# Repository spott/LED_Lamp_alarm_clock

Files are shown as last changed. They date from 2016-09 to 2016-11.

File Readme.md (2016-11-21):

# An LED alarm clock.  

Also known as a ESP8266 controlled PWM driver, lowish power AC Dimmer, and relay driver.  The schematic is available in PDF form in the PDFs folder, along with the PCB layout.

The ESP controls three different things here:

In the top right of the board, there are two optocouplers.  The ESP reads the voltage across the AC line using the ADC pin, and turns on a triac with GPIO12 (the `AC_CTRL1` net).  It can also turn on an SSR, a relay switch or some other load using `AC_CTRL2`.  `AC_CTRL2` and associated circuitry is on the left underneath the SMPS.

The bottom of the board contains the PWM control chip.  It has 16 LED outputs, of which 15 are broken out, and drive low V_th, and low gate charge N channel MOSFETs.  These act as low side switches for the pins that are next to them.  At the moment, the limit on the current that each can drive is the connector is the connector I believe.

This board is driven by a 12V input on the left side of the board, above the relay output.  The 12V is guided around the outside of the board in a rather wide copper pour on the bottom of the board, and is also used as the Vin of a SMPS that generates the 3.3V power for the ESP and PWM chip.

## Programming the board:

The programming of the ESP is done with a push switch (when the LED is lighted, the board is ready to run, when it is off, the board is waiting to be programmed), and a reset switch (the switch pulls reset low).  When the board is waiting to be programmed, a low signal on the DTR pin of the FTDI cable pulls CH_PD low, along with GPIO0 (hopefully, in case the switch is in the wrong position).

## Software:

Kicad 4.0.4 mostly, though some work was done with Kicad Master branch.

If you have trouble opening it with Kicad 4.0.4, submit an issue and I'll take care of it.

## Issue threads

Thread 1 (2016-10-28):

Reset method?

spott, 2016-10-28:
Maybe needs another reset method (either a way to power cycle the chip, or pull CH_PD low?

spott, 2016-11-06:
So, I think the best way to do this is using the `ck` upload_restartmethod in esptool and pio.

This means `RTS` controls RESET or CH_PD, `DTR` controls GPIO0.  This appears to work.

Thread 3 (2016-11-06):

Power supply stability control

spott, 2016-11-06:
* increase voltage of PS (will prevent brownouts from voltage dropping too low on current surge).
* increase capacitance near esp?

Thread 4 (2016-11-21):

footprint for mosfets flips source and gate.

spott, 2016-11-21:
:(  This kills the board.

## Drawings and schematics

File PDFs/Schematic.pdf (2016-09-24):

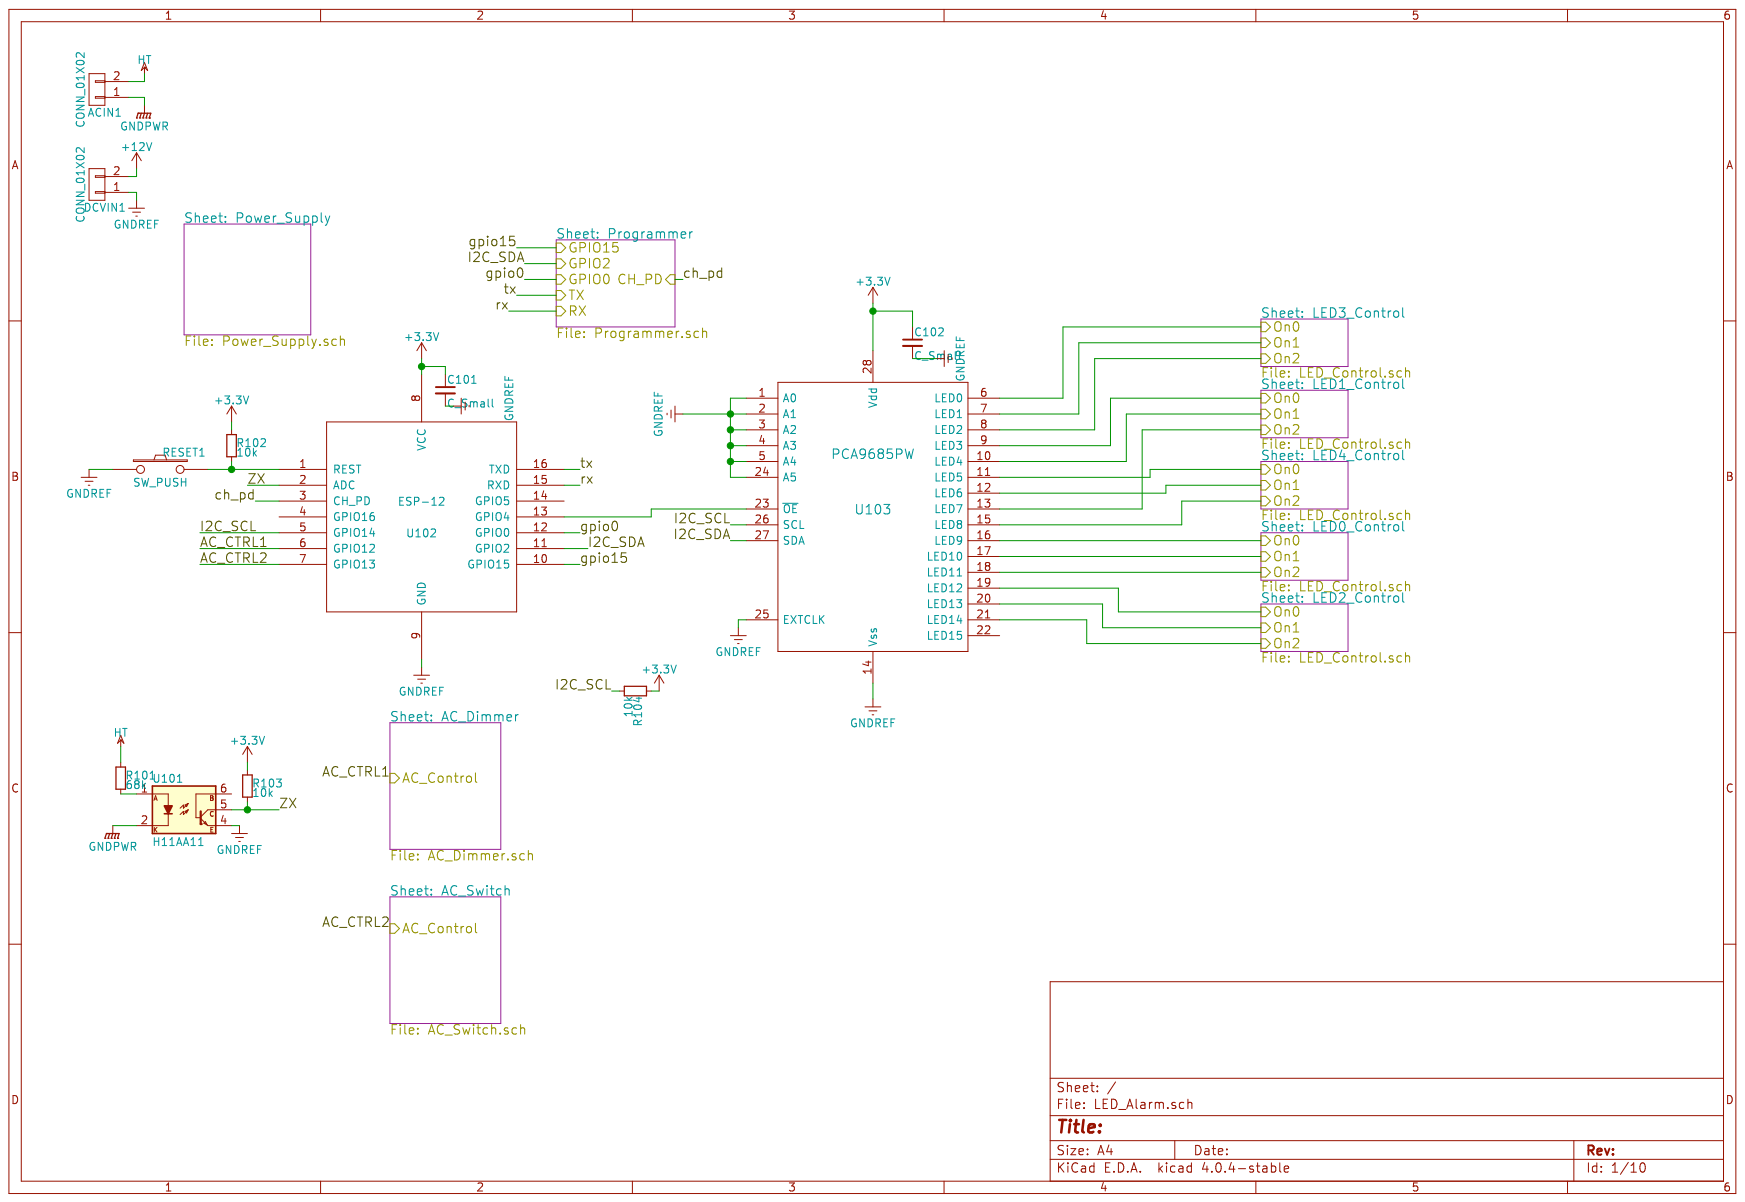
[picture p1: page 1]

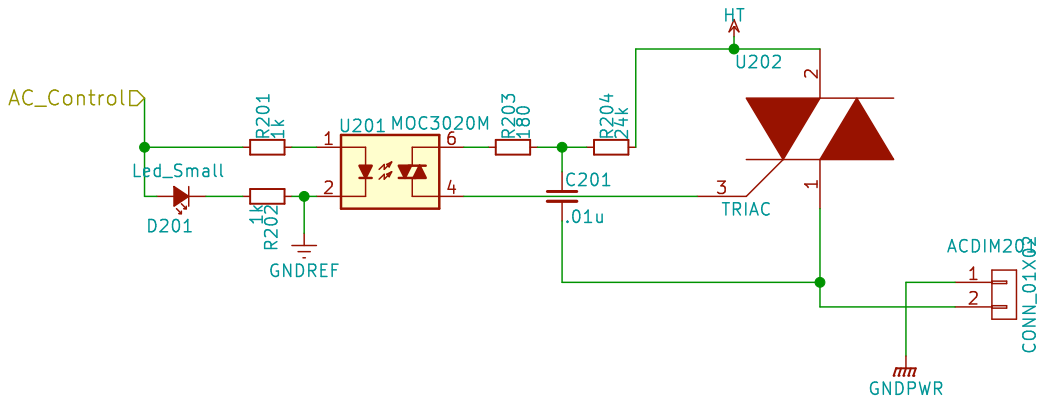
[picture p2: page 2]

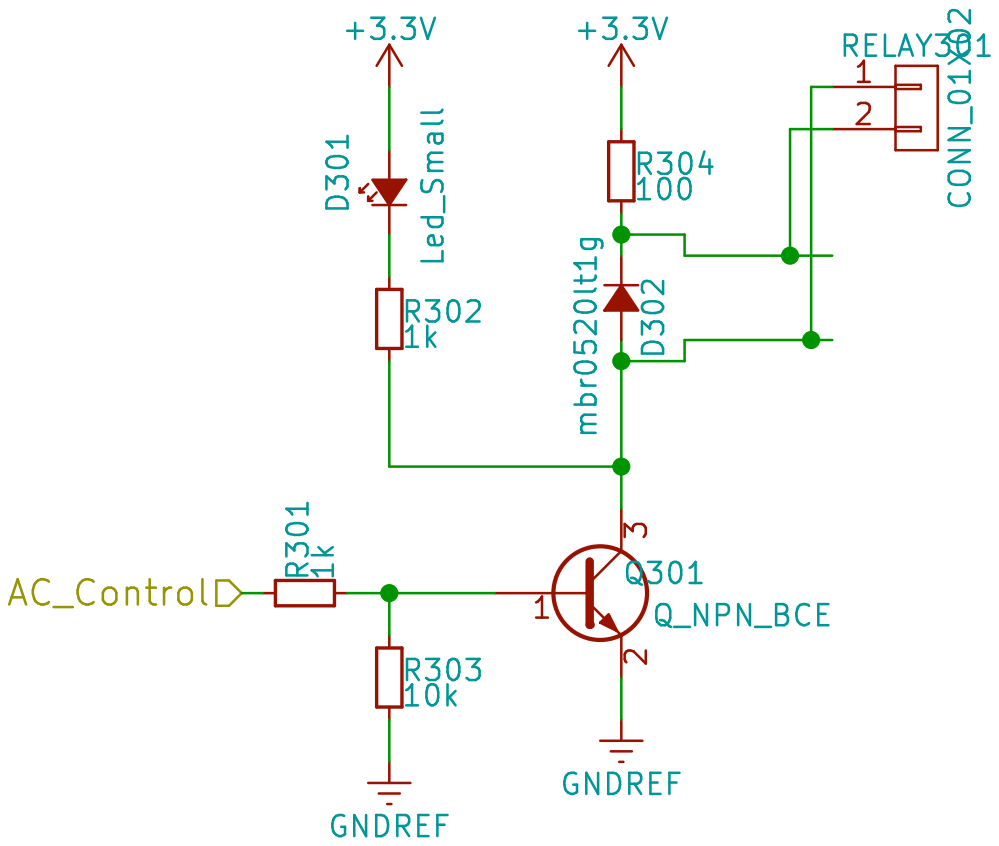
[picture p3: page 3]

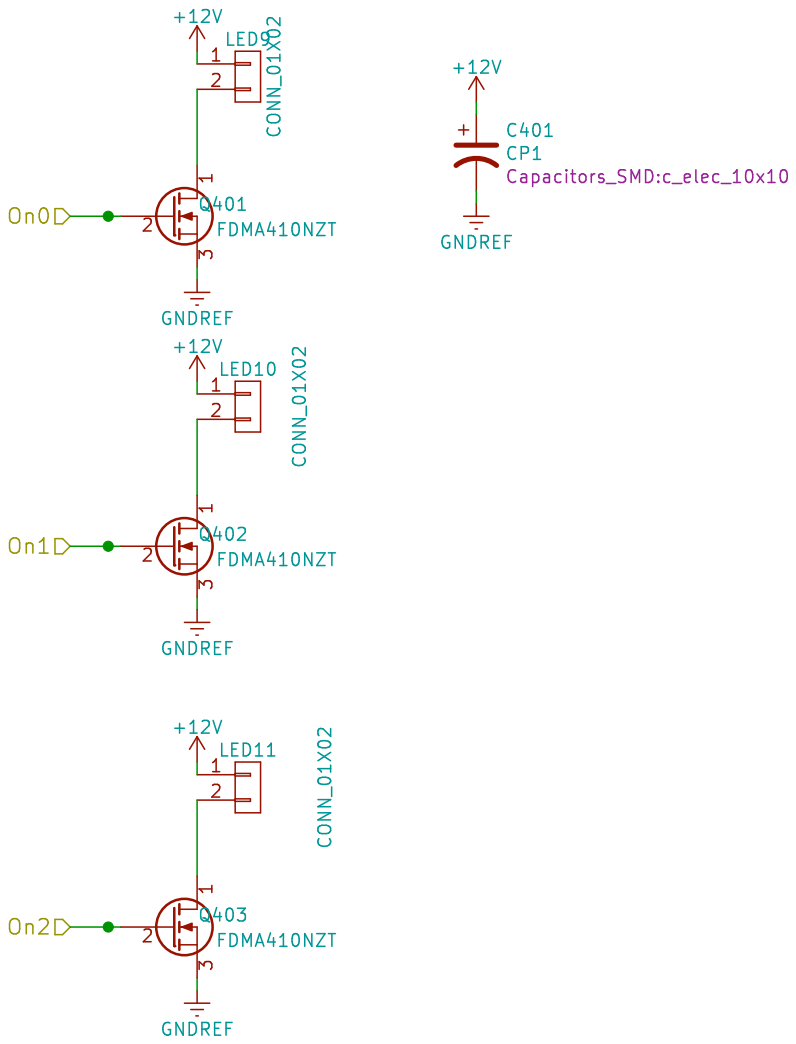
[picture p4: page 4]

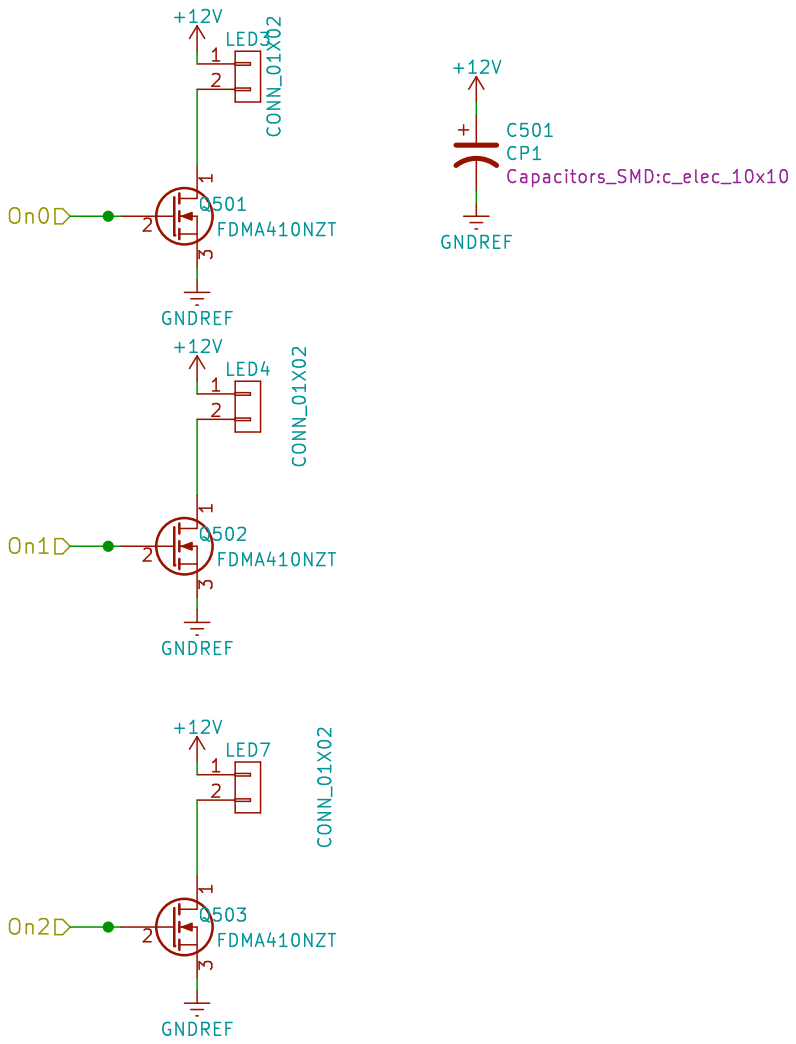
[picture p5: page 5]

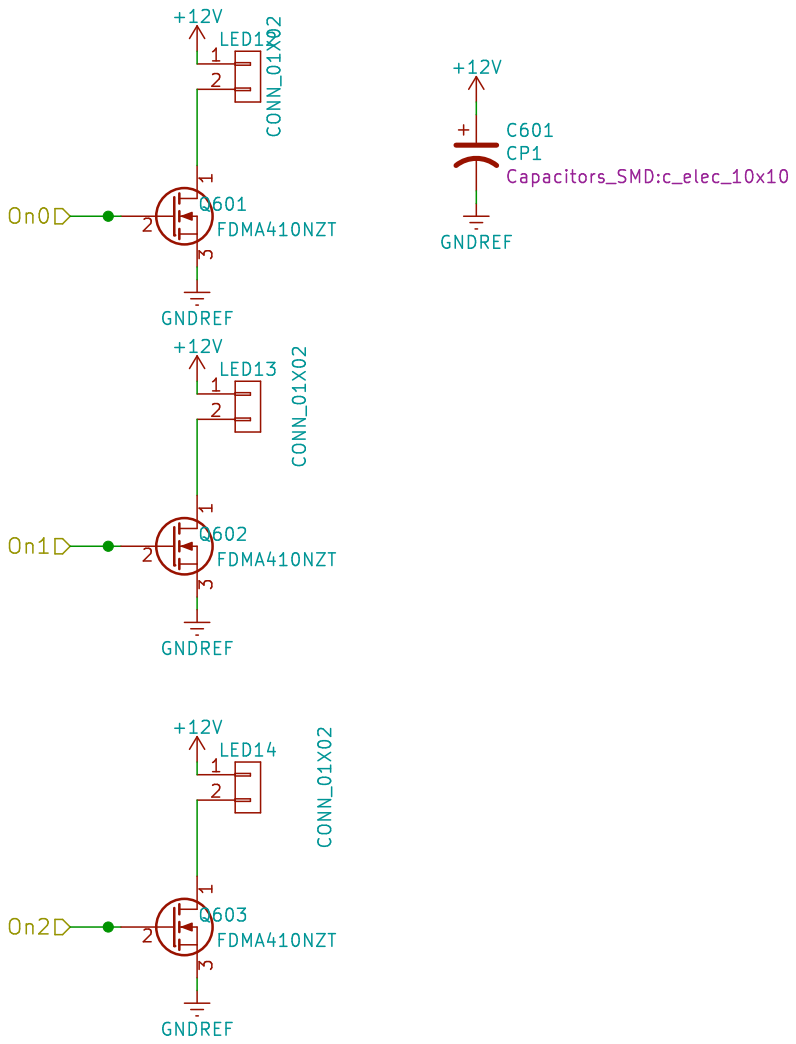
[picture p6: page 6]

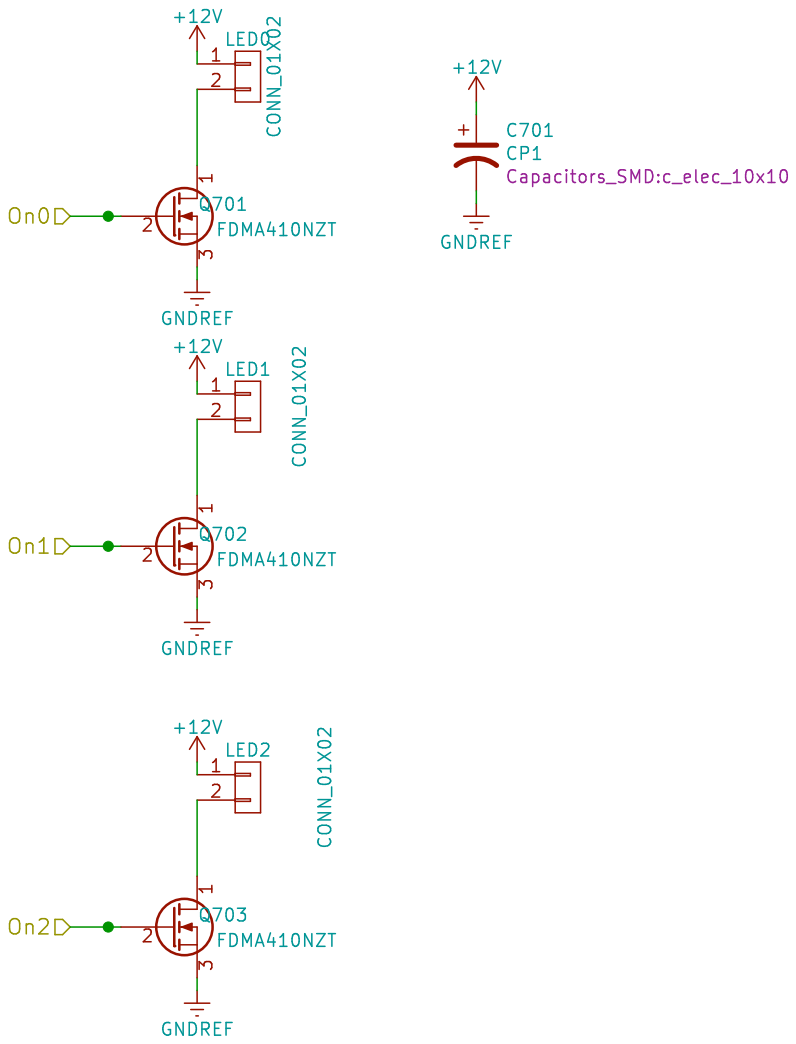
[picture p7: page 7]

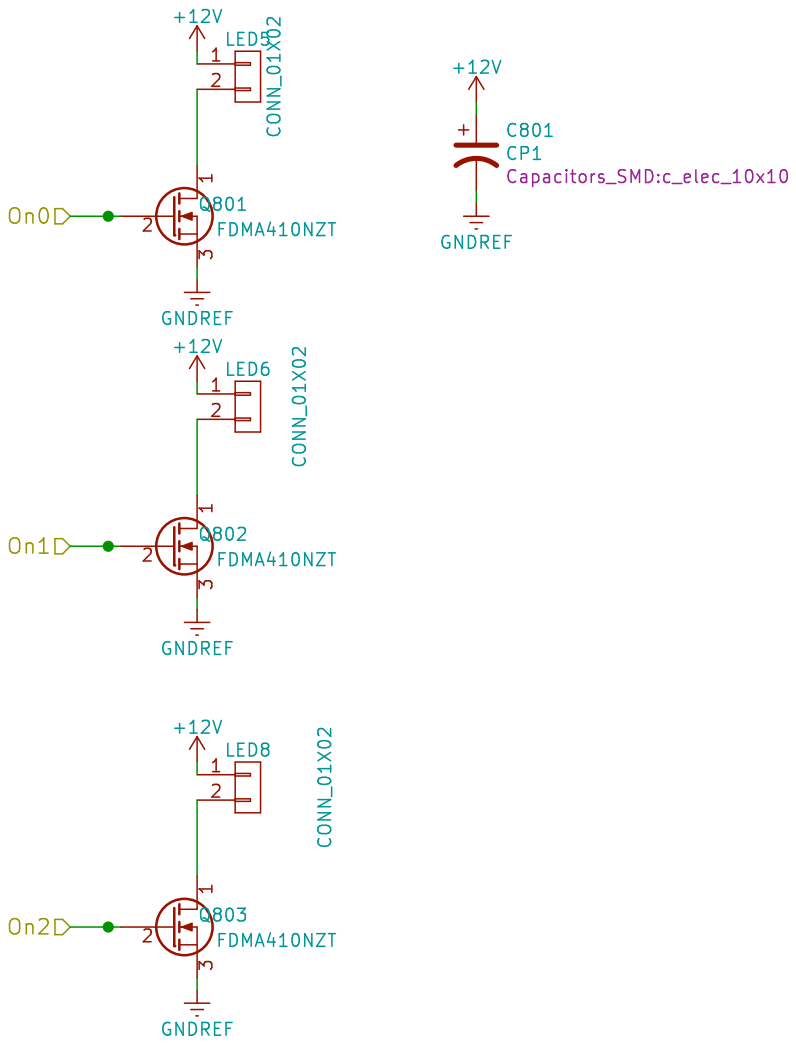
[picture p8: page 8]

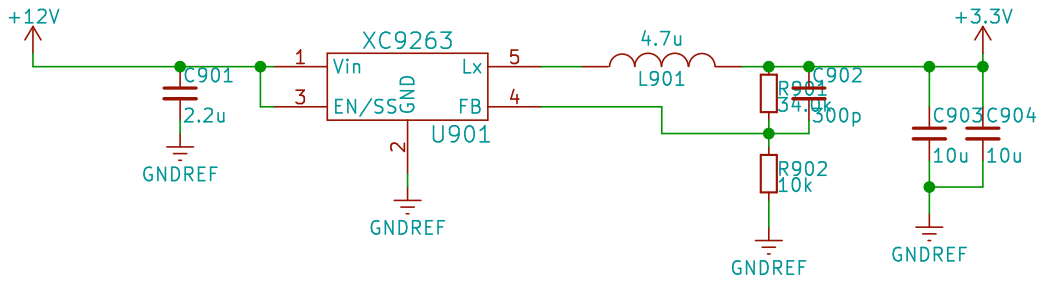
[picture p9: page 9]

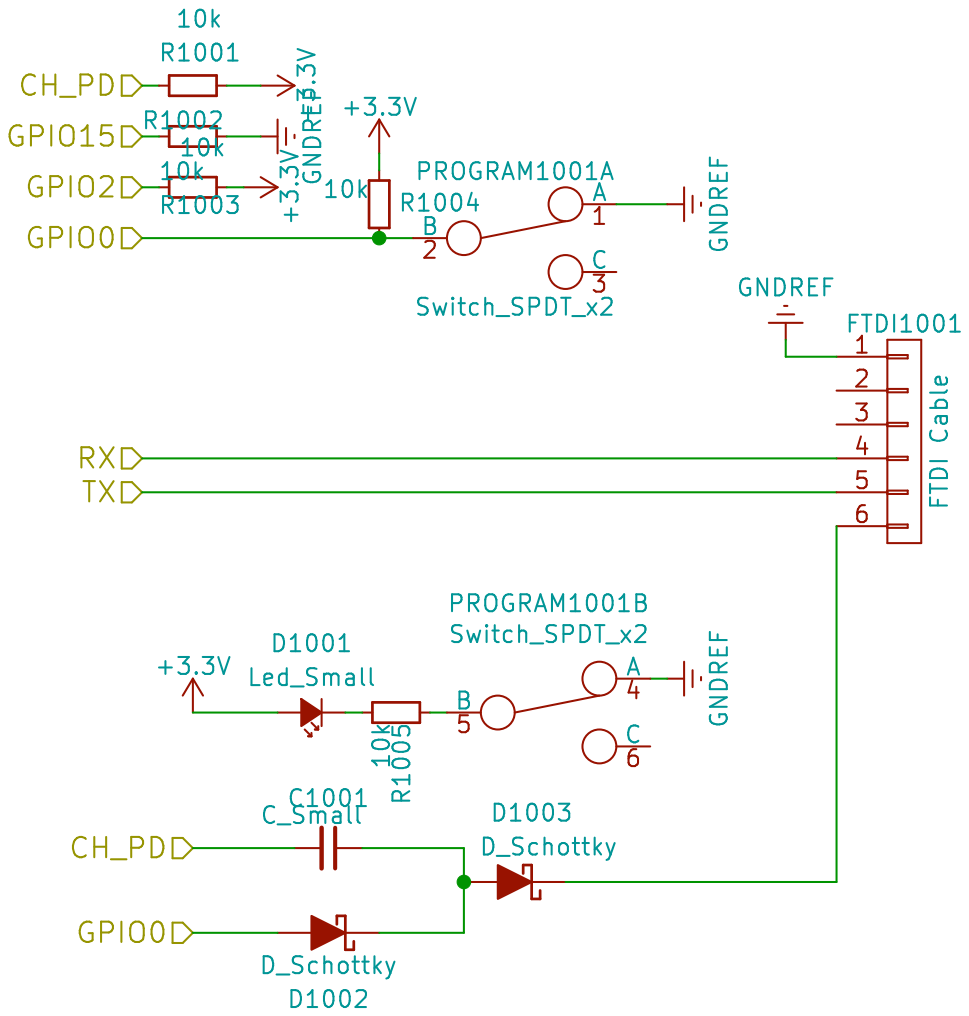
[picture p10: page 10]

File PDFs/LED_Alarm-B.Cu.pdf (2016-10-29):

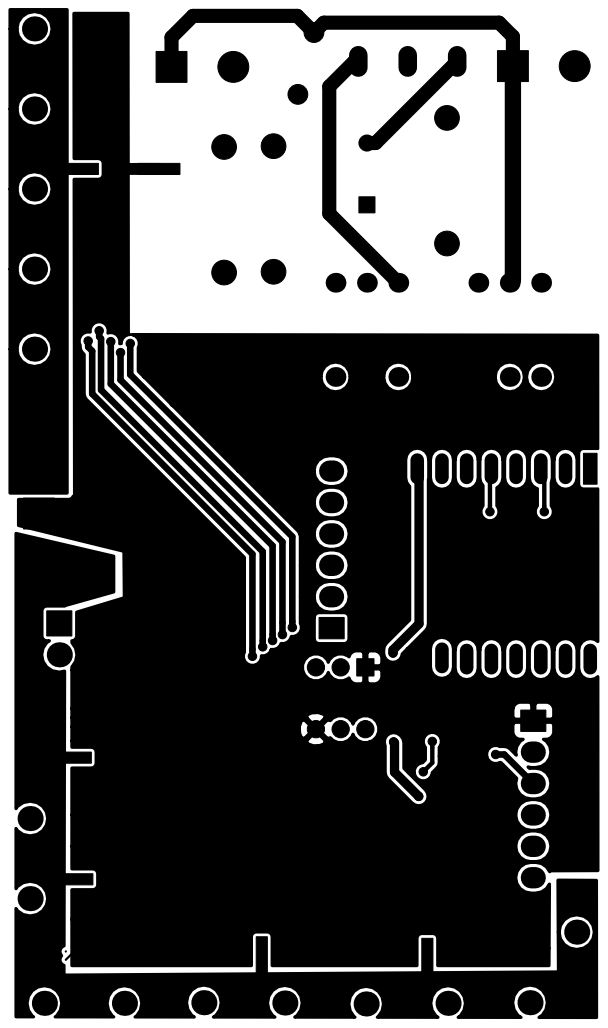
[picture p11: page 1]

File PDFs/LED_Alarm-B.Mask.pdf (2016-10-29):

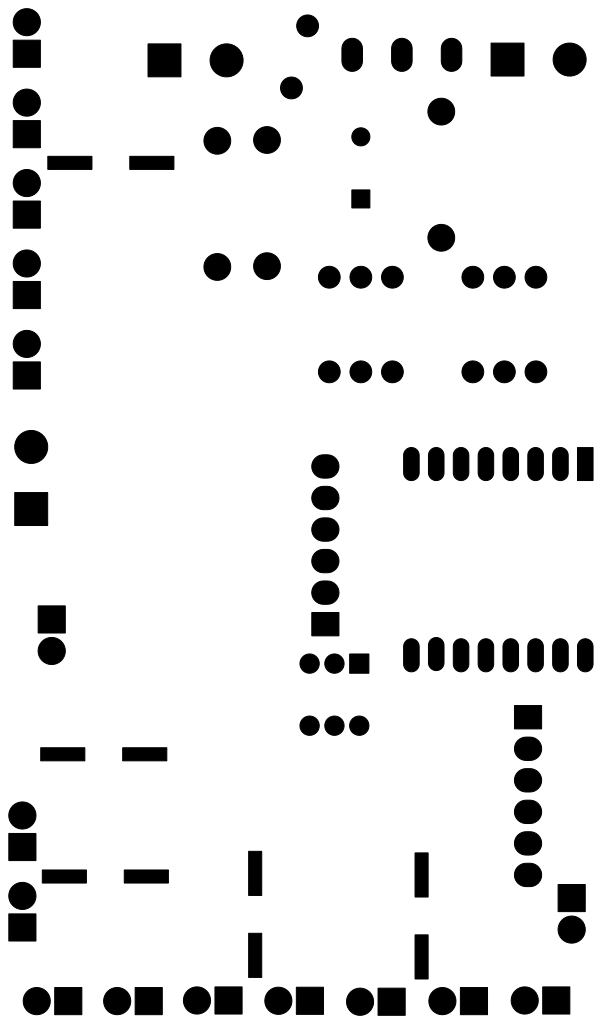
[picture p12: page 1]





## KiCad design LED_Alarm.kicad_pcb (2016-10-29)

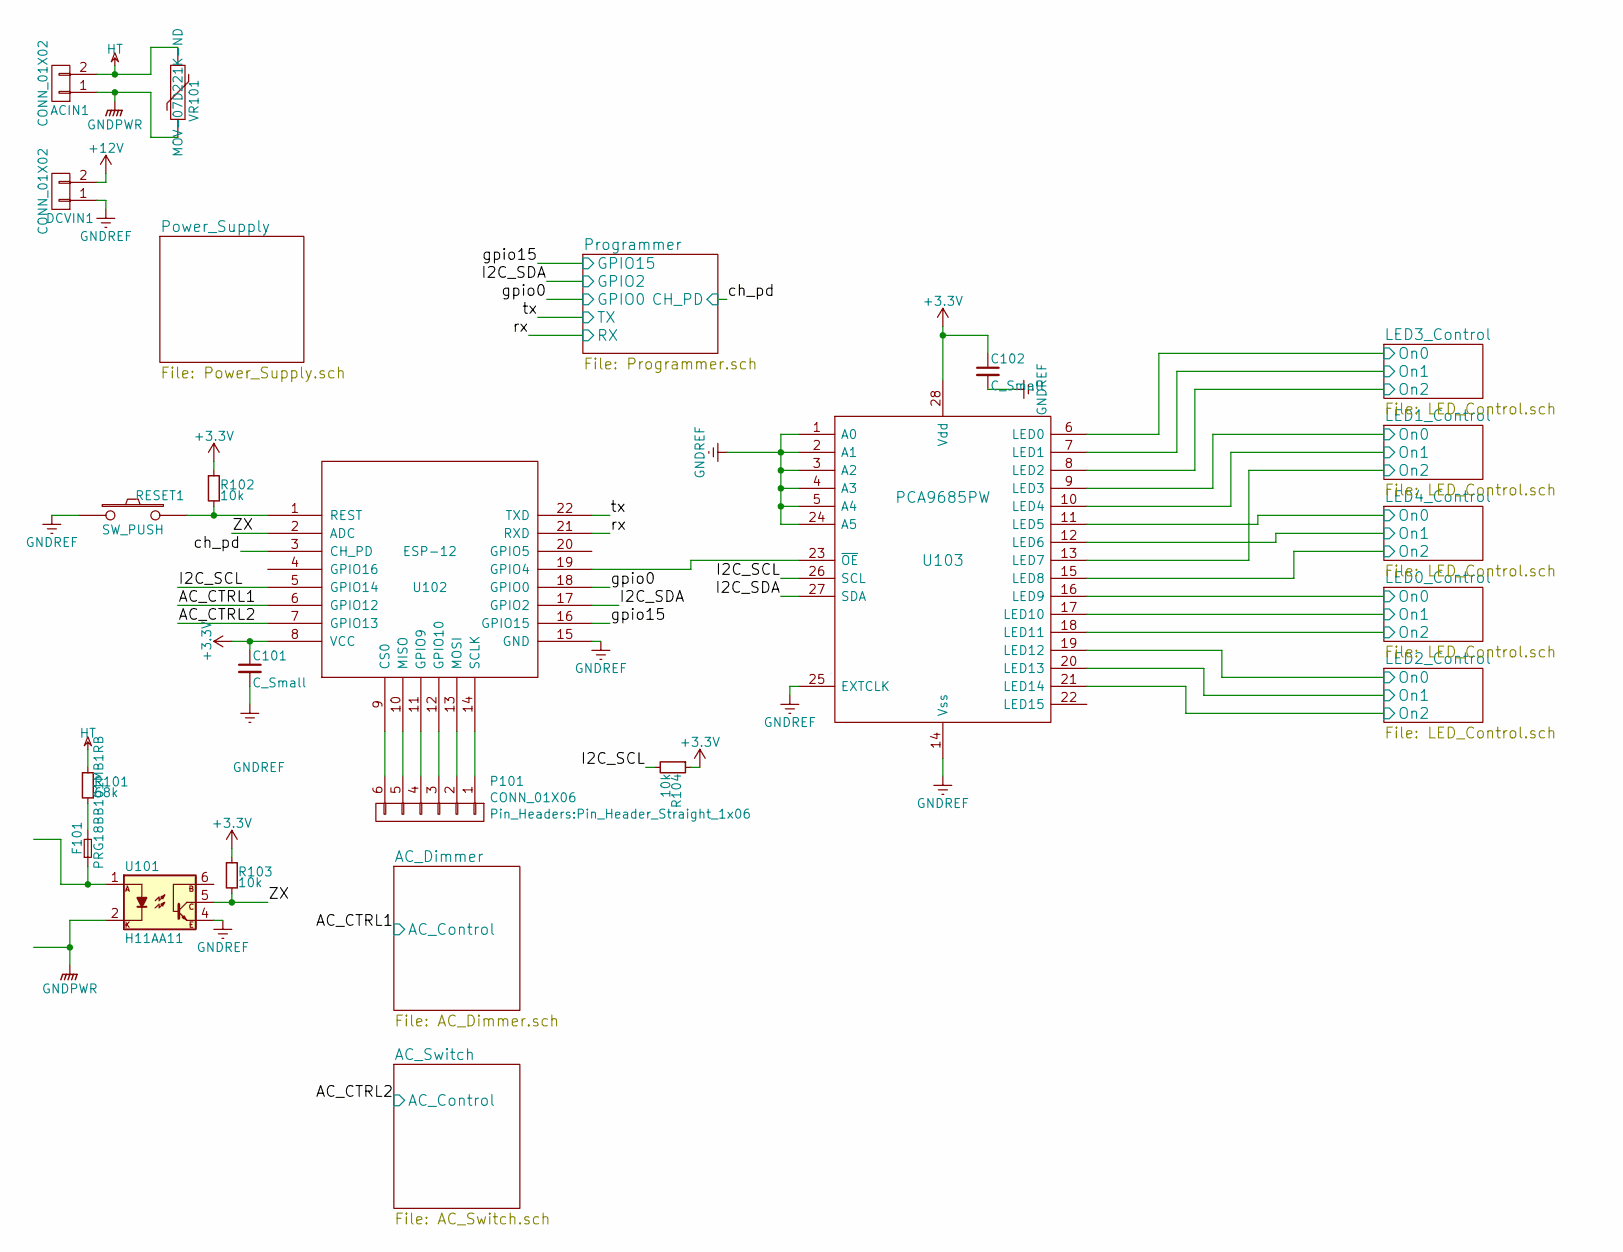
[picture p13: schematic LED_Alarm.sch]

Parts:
ACIN1: CONN_01X02; TerminalBlock_Pheonix_PT-3.5mm_2pol
C101, C102: C_Small; C_0603_HandSoldering
DCVIN1: CONN_01X02; TerminalBlock_Pheonix_MKDS1.5-2pol
F101: PRG18BB101MB1RB; R_0603_HandSoldering
P101: CONN_01X06; Pin_Header_Straight_1x06
R101: 68k; Resistor_Horizontal_RM10mm
R102, R103, R104: 10k; R_0603_HandSoldering
RESET1: SW_PUSH; SW_SPST_EVQQ2
U101: H11AA11; DIP-6_W7.62mm
U102: ESP-12; ESP-12E
U103: PCA9685PW; TSSOP-28_4.4x9.7mm_Pitch0.65mm
VR101: MOV-07D221K-ND; RV_Disc_D9_W3.5_P5

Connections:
+3V3: C101.1, C102.1, R102.1, R103.1, R104.1, U102.8 (VCC), U103.28 (Vdd); also elsewhere on the board
+12V: DCVIN1.2; also elsewhere on the board
/AC_CTRL1: U102.6 (GPIO12); also elsewhere on the board
/AC_CTRL2: U102.7 (GPIO13); also elsewhere on the board
/I2C_SCL: R104.2, U102.5 (GPIO14), U103.26 (SCL)
/I2C_SDA: U102.17 (GPIO2), U103.27 (SDA); also elsewhere on the board
/LED0_Control/On0: U103.16 (LED9); also elsewhere on the board
/LED0_Control/On1: U103.17 (LED10); also elsewhere on the board
/LED0_Control/On2: U103.18 (LED11); also elsewhere on the board
/LED1_Control/On0: U103.9 (LED3); also elsewhere on the board
/LED1_Control/On1: U103.10 (LED4); also elsewhere on the board
/LED1_Control/On2: U103.13 (LED7); also elsewhere on the board
/LED2_Control/On0: U103.19 (LED12); also elsewhere on the board
/LED2_Control/On1: U103.20 (LED13); also elsewhere on the board
/LED2_Control/On2: U103.21 (LED14); also elsewhere on the board
/LED3_Control/On0: U103.6 (LED0); also elsewhere on the board
/LED3_Control/On1: U103.7 (LED1); also elsewhere on the board
/LED3_Control/On2: U103.8 (LED2); also elsewhere on the board
/LED4_Control/On0: U103.11 (LED5); also elsewhere on the board
/LED4_Control/On1: U103.12 (LED6); also elsewhere on the board
/LED4_Control/On2: U103.15 (LED8); also elsewhere on the board
/ZX: R103.2, U101.5, U102.2 (ADC)
/ch_pd: U102.3 (CH_PD); also elsewhere on the board
/gpio0: U102.18 (GPIO0); also elsewhere on the board
/gpio15: U102.16 (GPIO15); also elsewhere on the board
/rx: U102.21 (RXD); also elsewhere on the board
/tx: U102.22 (TXD); also elsewhere on the board
GNDPWR: ACIN1.1, U101.2, VR101.2; also elsewhere on the board
GNDREF: C101.2, C102.2, DCVIN1.1, RESET1.1, U101.4, U102.15 (GND), U103.1 (A0), U103.2 (A1), U103.3 (A2), U103.4 (A3), U103.5 (A4), U103.14 (Vss), U103.24 (A5), U103.25 (EXTCLK); also elsewhere on the board
HT: ACIN1.2, R101.1, VR101.1; also elsewhere on the board
unnamed: F101.1, U101.1
unnamed: F101.2, R101.2
unnamed: P101.1, U102.14 (SCLK)
unnamed: P101.2, U102.13 (MOSI)
unnamed: P101.3, U102.12 (GPIO10)
unnamed: P101.4, U102.11 (GPIO9)
unnamed: P101.5, U102.10 (MISO)
unnamed: P101.6, U102.9 (CS0)
unnamed: R102.2, RESET1.2, U102.1 (REST)
unnamed: U102.19 (GPIO4), U103.23 (~OE)

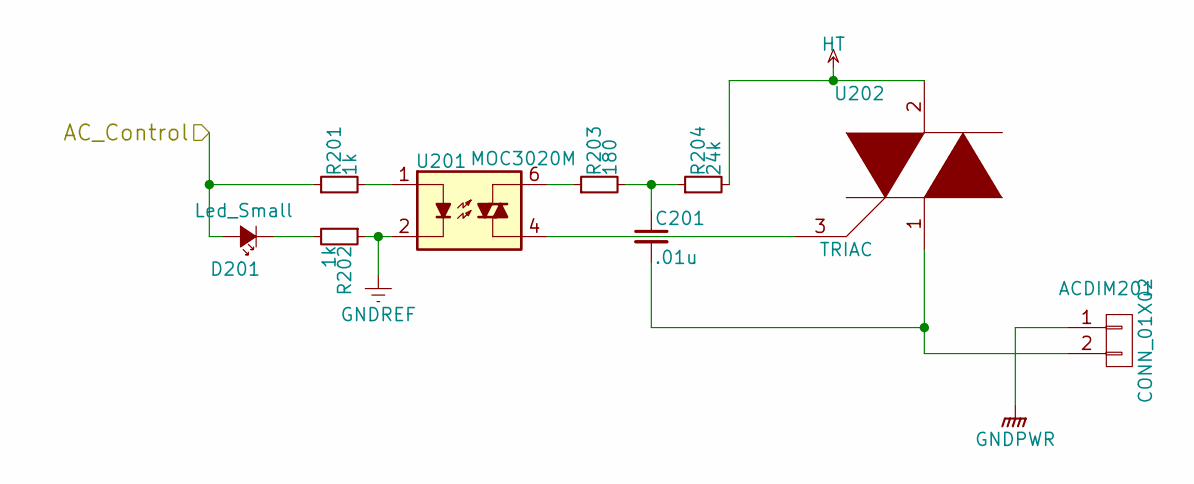
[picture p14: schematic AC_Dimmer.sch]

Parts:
ACDIM201: CONN_01X02; TerminalBlock_Pheonix_PT-3.5mm_2pol
C201: .01u; C_Rect_L7_W2.5_P5
D201: Led_Small; LED_0603
R201, R202: 1k; R_0603_HandSoldering
R203: 180; Resistor_Horizontal_RM10mm
R204: 24k; Resistor_Horizontal_RM10mm
U201: MOC3020M; DIP-6_W7.62mm
U202: TRIAC; TO-220_Neutral123_Vertical

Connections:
/AC_CTRL1: D201.2 (A), R201.1; also elsewhere on the board
GNDPWR: ACDIM201.1; also elsewhere on the board
GNDREF: R202.1, U201.2; also elsewhere on the board
HT: R204.2, U202.2; also elsewhere on the board
unnamed: ACDIM201.2, C201.2, U202.1
unnamed: C201.1, R203.2, R204.1
unnamed: D201.1 (K), R202.2
unnamed: R201.2, U201.1
unnamed: R203.1, U201.6
unnamed: U201.4, U202.3

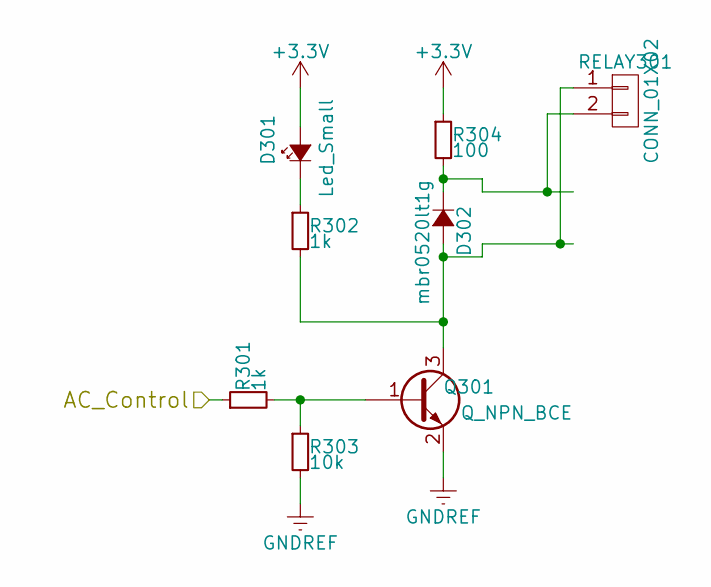
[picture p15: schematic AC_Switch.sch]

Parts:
D301: Led_Small; LED_0603
D302: mbr0520lt1g; SOD-123
Q301: Q_NPN_BCE; SOT-23_Handsoldering
R301, R302: 1k; R_0603_HandSoldering
R303: 10k; R_0603_HandSoldering
R304: 100; R_0603_HandSoldering
RELAY301: CONN_01X02; Pin_Header_Straight_1x02

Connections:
+3V3: D301.2 (A), R304.1; also elsewhere on the board
/AC_CTRL2: R301.1; also elsewhere on the board
GNDREF: Q301.2 (E), R303.2; also elsewhere on the board
unnamed: D301.1 (K), R302.1
unnamed: D302.1 (K), R304.2, RELAY301.2
unnamed: D302.2 (A), Q301.3 (C), R302.2, RELAY301.1
unnamed: Q301.1 (B), R301.2, R303.1

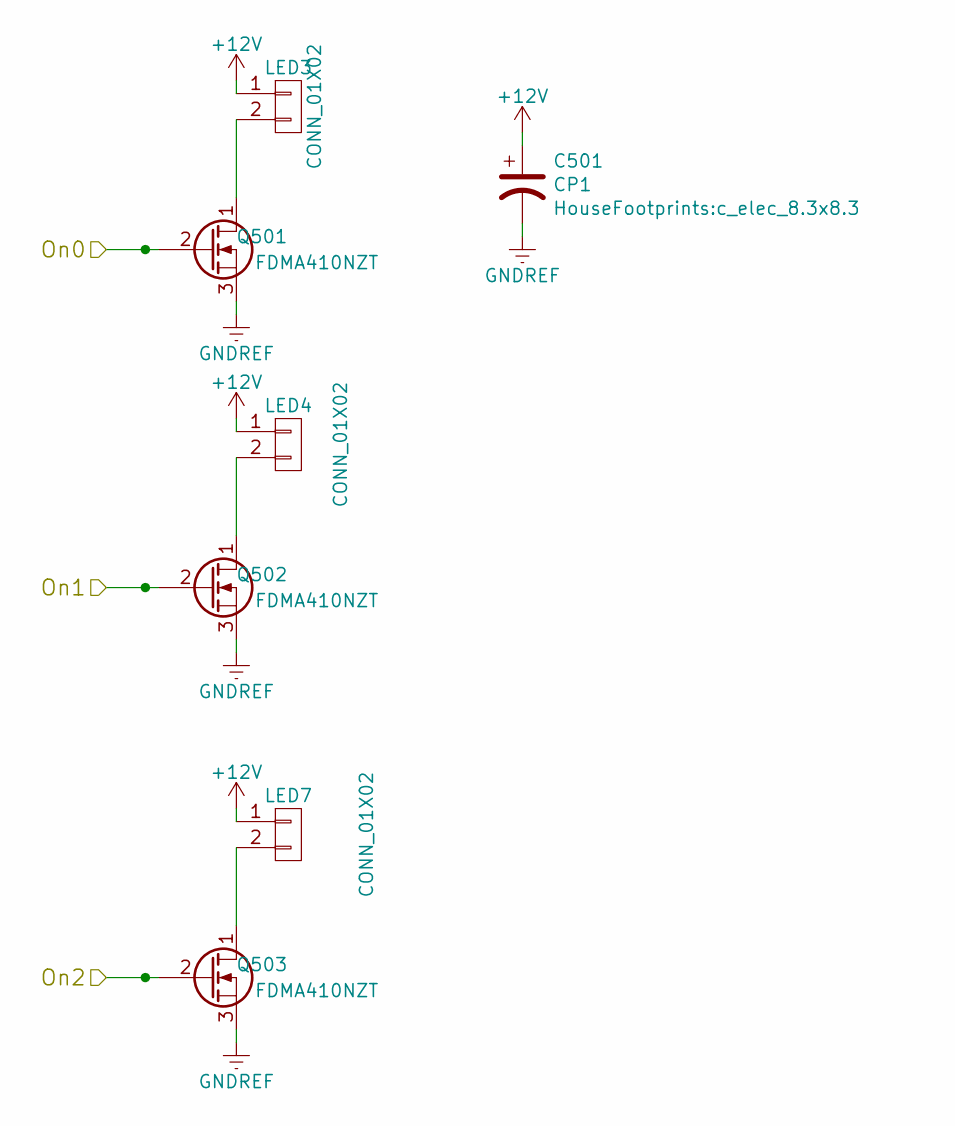
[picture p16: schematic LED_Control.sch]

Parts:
C401: CP1; c_elec_8.3x8.3
LED9, LED10, LED11: CONN_01X02; Pin_Header_Straight_1x02
Q401, Q402, Q403: FDMA410NZT; MicroFET-6

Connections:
+12V: C401.1, LED9.1, LED10.1, LED11.1; also elsewhere on the board
/LED0_Control/On0: Q401.2 (G); also elsewhere on the board
/LED0_Control/On1: Q402.2 (G); also elsewhere on the board
/LED0_Control/On2: Q403.2 (G); also elsewhere on the board
GNDREF: C401.2, Q401.3 (S), Q402.3 (S), Q403.3 (S); also elsewhere on the board
unnamed: LED9.2, Q401.1 (D)
unnamed: LED10.2, Q402.1 (D)
unnamed: LED11.2, Q403.1 (D)

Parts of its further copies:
C501, C601, C701, C801: CP1; c_elec_8.3x8.3
LED0, LED1, LED2, LED3, LED4, LED5, LED6, LED7, LED8, LED12, LED13, LED14: CONN_01X02; Pin_Header_Straight_1x02
Q501, Q502, Q503, Q601, Q602, Q603, Q701, Q702, Q703, Q801, Q802, Q803: FDMA410NZT; MicroFET-6

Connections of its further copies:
+12V: C501.1, C601.1, C701.1, C801.1, LED0.1, LED1.1, LED2.1, LED3.1, LED4.1, LED5.1, LED6.1, LED7.1, LED8.1, LED12.1, LED13.1, LED14.1; also elsewhere on the board
/LED1_Control/On0: Q501.2 (G); also elsewhere on the board
/LED1_Control/On1: Q502.2 (G); also elsewhere on the board
/LED1_Control/On2: Q503.2 (G); also elsewhere on the board
/LED2_Control/On0: Q601.2 (G); also elsewhere on the board
/LED2_Control/On1: Q602.2 (G); also elsewhere on the board
/LED2_Control/On2: Q603.2 (G); also elsewhere on the board
/LED3_Control/On0: Q701.2 (G); also elsewhere on the board
/LED3_Control/On1: Q702.2 (G); also elsewhere on the board
/LED3_Control/On2: Q703.2 (G); also elsewhere on the board
/LED4_Control/On0: Q801.2 (G); also elsewhere on the board
/LED4_Control/On1: Q802.2 (G); also elsewhere on the board
/LED4_Control/On2: Q803.2 (G); also elsewhere on the board
GNDREF: C501.2, C601.2, C701.2, C801.2, Q501.3 (S), Q502.3 (S), Q503.3 (S), Q601.3 (S), Q602.3 (S), Q603.3 (S), Q701.3 (S), Q702.3 (S), Q703.3 (S), Q801.3 (S), Q802.3 (S), Q803.3 (S); also elsewhere on the board
unnamed: LED0.2, Q701.1 (D)
unnamed: LED1.2, Q702.1 (D)
unnamed: LED2.2, Q703.1 (D)
unnamed: LED3.2, Q501.1 (D)
unnamed: LED4.2, Q502.1 (D)
unnamed: LED5.2, Q801.1 (D)
unnamed: LED6.2, Q802.1 (D)
unnamed: LED7.2, Q503.1 (D)
unnamed: LED8.2, Q803.1 (D)
unnamed: LED12.2, Q601.1 (D)
unnamed: LED13.2, Q602.1 (D)
unnamed: LED14.2, Q603.1 (D)

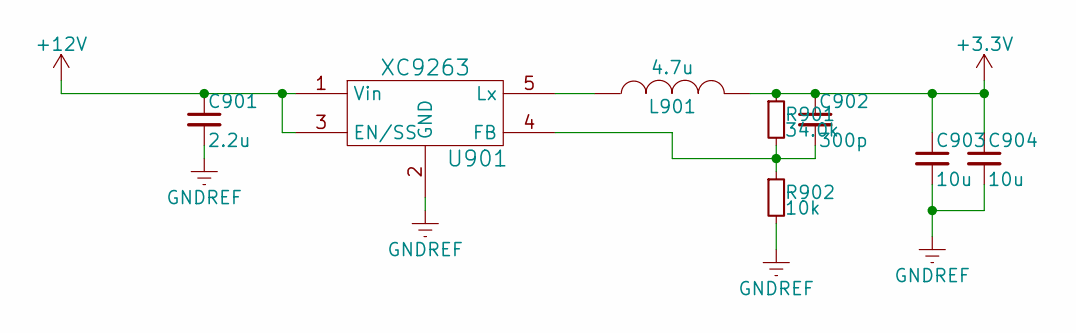
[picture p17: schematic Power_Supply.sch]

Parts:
C901: 2.2u; C_0603_HandSoldering
C902: 300p; C_0603_HandSoldering
C903, C904: 10u; C_0603_HandSoldering
L901: 4.7u; CLF6045NI-D-Inductor
R901: 34.0k; R_0603_HandSoldering
R902: 10k; R_0603_HandSoldering
U901: XC9263; SOT-25

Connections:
+3V3: C902.1, C903.1, C904.1, L901.2, R901.1; also elsewhere on the board
+12V: C901.1, U901.1 (Vin), U901.3 (EN/SS); also elsewhere on the board
GNDREF: C901.2, C903.2, C904.2, R902.2, U901.2 (GND); also elsewhere on the board
unnamed: C902.2, R901.2, R902.1, U901.4 (FB)
unnamed: L901.1, U901.5 (Lx)

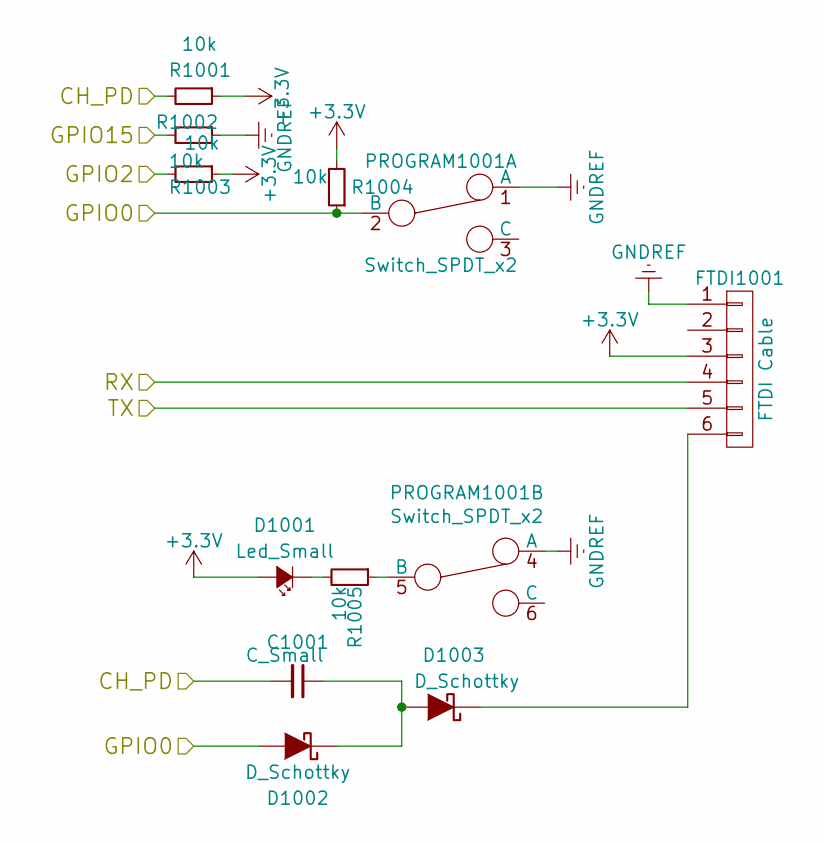
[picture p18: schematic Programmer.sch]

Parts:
C1001: C_Small; C_0603_HandSoldering
D1001: Led_Small; LED_0603
D1002, D1003: D_Schottky; SOD-323
FTDI1001: FTDI Cable; Pin_Header_Straight_1x06
PROGRAM1001: Switch_SPDT_x2; SW_PUSH_DPDT
R1001, R1002, R1003, R1004, R1005: 10k; R_0603_HandSoldering

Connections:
+3V3: D1001.2 (A), FTDI1001.3, R1001.1, R1003.1, R1004.2; also elsewhere on the board
/I2C_SDA: R1003.2; also elsewhere on the board
/ch_pd: C1001.2, R1001.2; also elsewhere on the board
/gpio0: D1002.2 (A), PROGRAM1001.2 (B), R1004.1; also elsewhere on the board
/gpio15: R1002.2; also elsewhere on the board
/rx: FTDI1001.4; also elsewhere on the board
/tx: FTDI1001.5; also elsewhere on the board
GNDREF: FTDI1001.1, PROGRAM1001.1 (A), PROGRAM1001.4 (A), R1002.1; also elsewhere on the board
unnamed: C1001.1, D1002.1 (K), D1003.2 (A)
unnamed: D1001.1 (K), R1005.2
unnamed: D1003.1 (K), FTDI1001.6
unnamed: PROGRAM1001.5 (B), R1005.1

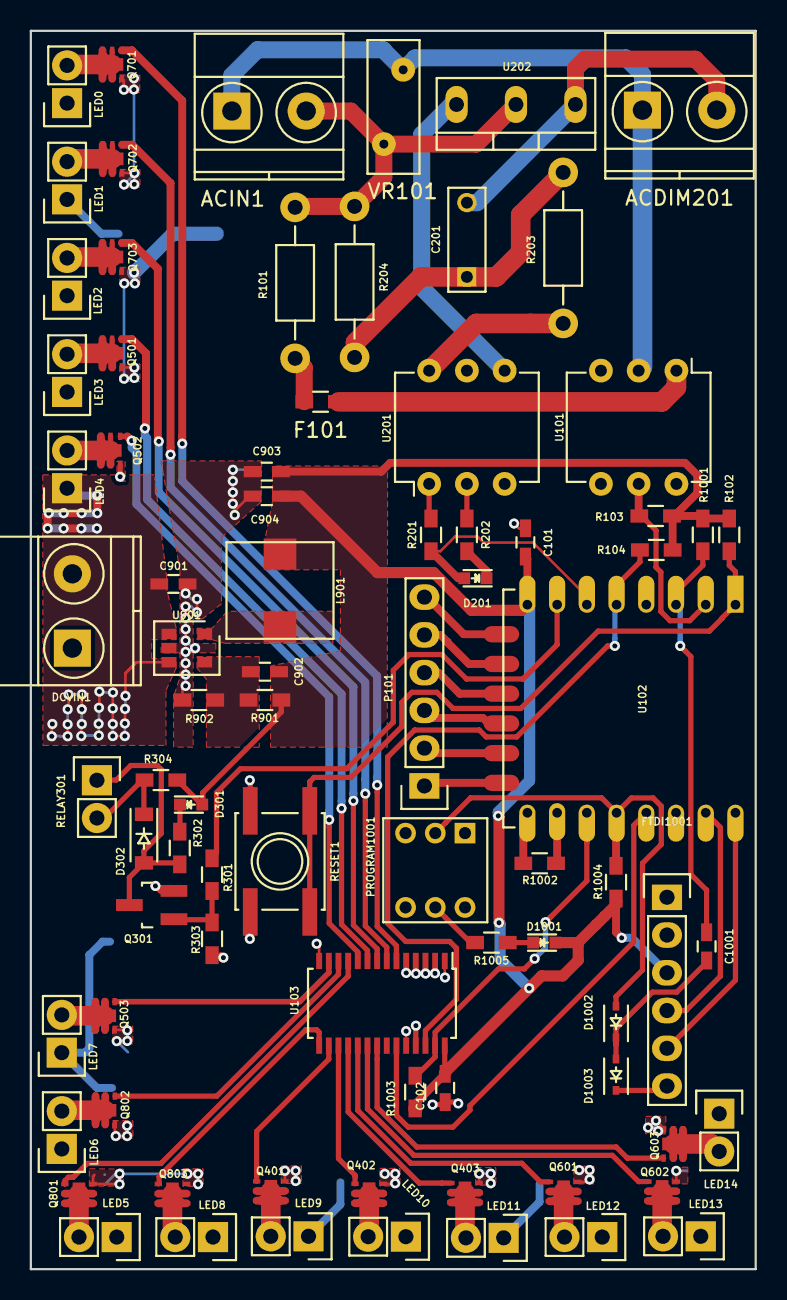
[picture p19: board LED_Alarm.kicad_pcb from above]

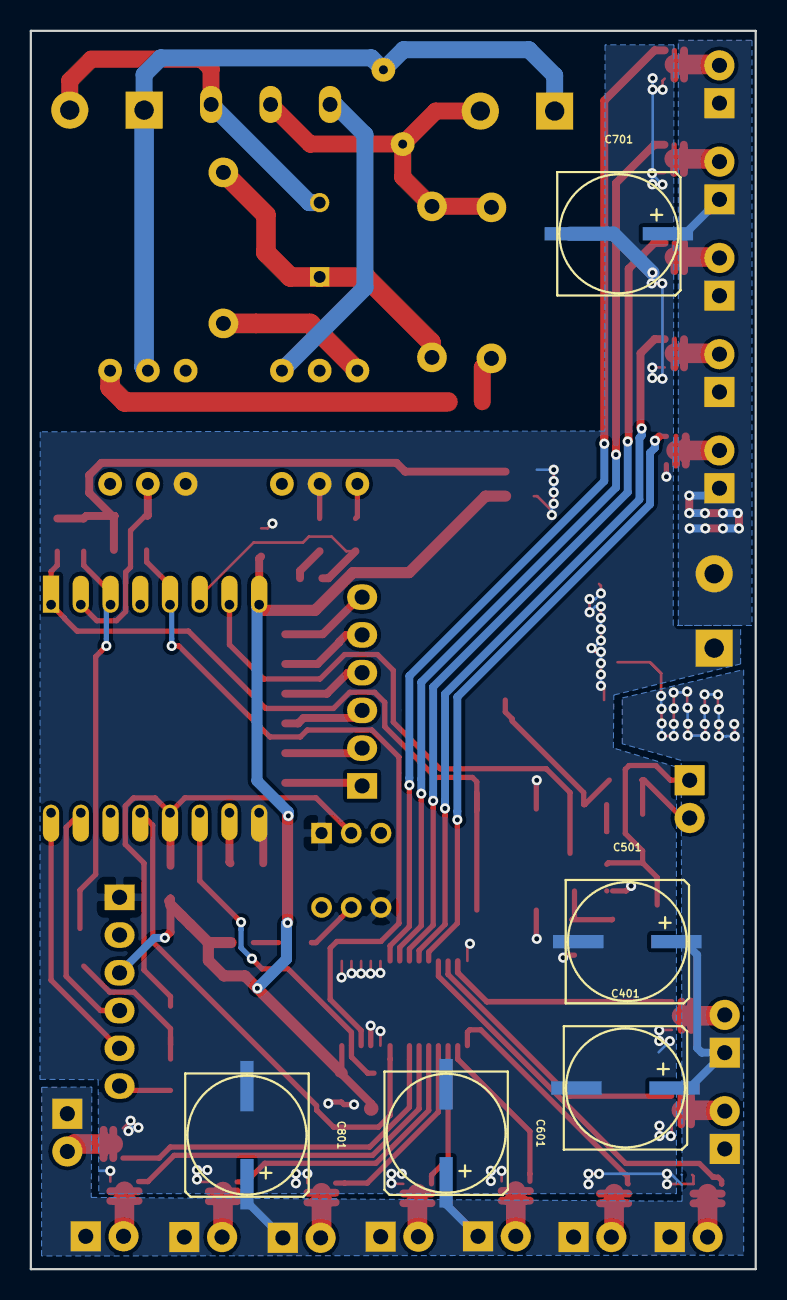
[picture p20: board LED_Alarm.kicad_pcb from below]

Board: 2 copper layers, 48.8 x 83.3 mm, 86 parts (5 on the bottom side), 71 nets.

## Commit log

2016-09-24 initial commit, pretty much done
    [AC_Dimmer.sch, AC_Switch.sch, LED_Alarm.kicad_pcb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]
2016-09-24 modified gitignore to ignore gerber files
2016-09-26 After changes suggested in https://www.reddit.com/r/PrintedCircuitBoard/comments/54ctxv/pcb_review_of_a_pwm_esp8266_led_driver_board/
    [LED_Alarm.kicad_pcb, LED_Alarm.sch, LED_Control.sch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]
2016-10-29 changed some stuff around
    [LED_Alarm.kicad_pcb, LED_Alarm.sch, LED_Control.sch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]
